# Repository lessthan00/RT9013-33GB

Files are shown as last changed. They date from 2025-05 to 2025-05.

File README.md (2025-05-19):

# RT9013-33GB

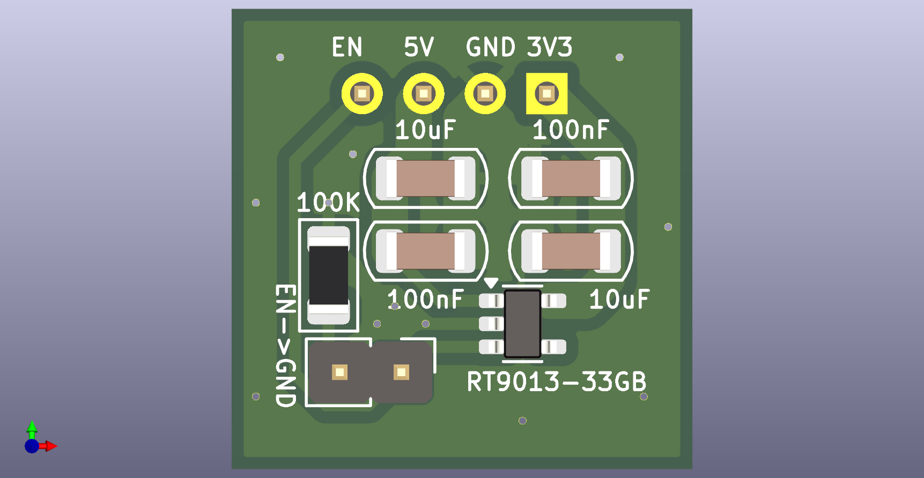
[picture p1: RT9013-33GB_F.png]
  
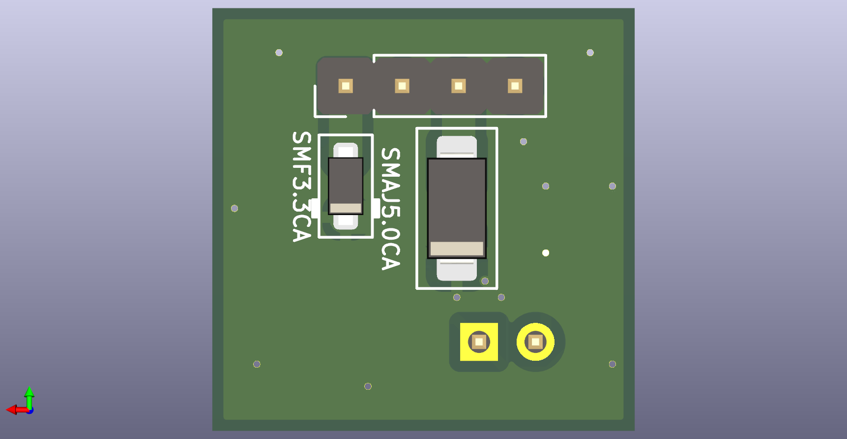
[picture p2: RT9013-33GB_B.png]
  
  

[RT9013-33GB](https://www.jlc-smt.com/lcsc/detail?componentCode=C47773)
LDO
VIN 5.5V
VOUT 3.3V
IOUT 0.5A
package SOT-23-5
accuracy 2%
IQ 50uA
VD 250mV@500mA
ENL 0.6V
ENH 1.6V
IEN 0.1uA -> 100K电阻

引脚定义
1-VIN
2-GND
3-EN
4-NC
5-VOUT

## ME6211C33M5G-N board = RT9013-33GB

[ME6211C33M5G-N](https://www.jlc-smt.com/lcsc/detail?componentCode=C82942)
LDO
VIN 6V
VOUT 3.3V
IOUT 300mA
package SOT-23-5
accuracy 2%
IQ 60uA
VD 260mV@200mA
ENL 0.5V
ENH 1V
IEN 应该是uA -> 100K电阻
Vn 50uVrms

引脚定义
1-VIN
2-GND
3-EN
4-NC
5-VOUT

## ME6210A33PG borad change from AMS1117-3V3

[ME6210A33PG](https://www.jlc-smt.com/lcsc/detail?componentCode=C85233)  
LDO  
VIN 18V  
VOUT 3.3V  
IOUT 500mA  
package SOT-89-3  
IQ 2.5uA  
VD 260mV@200mA  

引脚定义  
1-GND  
2-VIN  
3-VOUT  

## HT7550-1 board = ME6210A33PG  

[HT7550-1](https://www.jlc-smt.com/lcsc/detail?componentCode=C5346140)
LDO  
VIN 28V  
VOUT 5V  
IOUT 150mA  
package SOT-89-3
accuracy 2%
IQ 4uA
VD 520mA@100mA  

引脚定义  
1-GND  
2-IN  
3-VOUT  

## ME6206A33XG  borad change from AMS1117-3V3
  
[ME6206A33XG](https://www.jlc-smt.com/lcsc/detail?componentCode=C161345)  
LDO  
VIN 6V  
VOUT 3.3V  
IOUT 300mA  
package SOT-23-3  
IQ 8uA  
VD 400mV@200mA  

引脚定义  
1-GND  
2-VOUT  
3-VIN  

kciad 并无其符号, 根据封装和引脚定义, 选择自MCP1703Ax-330xxTT 这个符号派生  
封装也是取其 Package_TO_SOT_SMD:SOT-23  
输入TVS 改为 SMAJ6.0CA  

## AMS1117-3V3  borad change from HT7333
  
[AMS1117-3V3](https://www.jlc-smt.com/lcsc/detail?componentCode=C5120765)  
LDO  
  
VIN 18V  
VOUT 3.3V  
IOUT 1A  
package SOT-223  
IQ 12mA  
VD 1.4V@1A  
  
引脚引脚定义  
  
1 GND  
2 VOUT  
3 VIN  

输入TVS 改为SMAJ18CA
  
## HT7333  
  
[HT7333](https://item.szlcsc.com/323851.html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)  
  
LDO  
  
VIN 12V  
VOUT 3.3V  
IOUT 250mA  
package SOT-89-3  
IQ 3uA  
VD 90mV@40mA  
  
引脚定义  
  
1 GND  
2 VIN  
3 VOUT  
  
所以使用kciad 里面的 Regulator_Generic_GND_IN_OUT 生成符号  
  
封装采用PCM_Package_TO_SOT_SMD_AKL:SOT-89-3, 已确认封装焊盘顺序定义无误  
  
## TLV70450DBVR  
  
[TLV70450DBVR](https://www.jlc-smt.com/lcsc/detail?componentCode=C91672)  
VIN 24V  
VOUT 5V  
IOUT 150mA  
IQ 4.5uA  
VD 1.1V@100mA  
package SOT-23-5  
  
1-GND  
2-IN  
3-OUT  
4-NC  
5-NC  
  
这样的封装的引脚定义是很少的,基本上只有TLV70450DBVR,甚至需要自己绘制封装...  

## KP3310SGA

[KP3310SGA](http://www.kiwiinst.com/productinfo/1249602.html)  
高压斩波 + LDOLDO  
VIN 80~305VAC  
VOUT 5V/3.3V/2.7V  
IOUT 30mA  
耐压 650V MOS  
RS(ON) 9.5Ω  
IQ 130uA  
无法获取详细资料,放弃做板子

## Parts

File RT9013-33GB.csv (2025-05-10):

Reference | Qty | Value | DNP | Exclude from BOM | Exclude from Board | Footprint | Datasheet
C1,C3 | 2 | 10uF |  |  |  | PCM_Capacitor_SMD_AKL:C_1206_3216Metric | ~
C2,C4 | 2 | 100nF |  |  |  | PCM_Capacitor_SMD_AKL:C_1206_3216Metric | ~
D1 | 1 | SMAJ5.0CA |  |  |  | PCM_Diode_SMD_AKL:D_SMA_TVS | https://www.tme.eu/Document/dbc72d81c249fe51b6ab42300e8e06d0/SMAJ_ser.pdf
D2 | 1 | SMF3.3CA |  |  |  | PCM_Diode_SMD_AKL:D_SOD-123F | https://item.szlcsc.com/48682096.html?fromZone=s_s__%2522SMF3.3CA%2522
J2 | 1 | Conn_01x02 |  |  |  | Connector_PinHeader_2.54mm:PinHeader_1x02_P2.54mm_Vertical | ~
J3 | 1 | Conn_01x04 |  |  |  | Connector_PinHeader_2.54mm:PinHeader_1x04_P2.54mm_Vertical | ~
R1 | 1 | 100K |  |  |  | PCM_Resistor_SMD_AKL:R_1206_3216Metric | ~
U1 | 1 | RT9013-33GB |  |  |  | Package_TO_SOT_SMD:SOT-23-5 | https://www.jlc-smt.com/lcsc/detail?componentCode=C47773

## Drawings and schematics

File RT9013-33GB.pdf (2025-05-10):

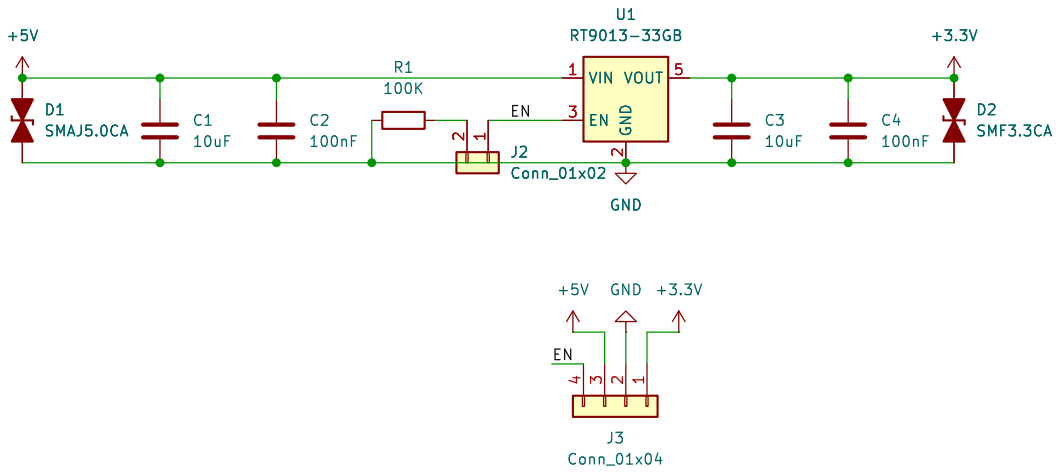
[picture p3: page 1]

Id: 1/1 Title: File: RT9013-33GB.kicad_sch Sheet: /

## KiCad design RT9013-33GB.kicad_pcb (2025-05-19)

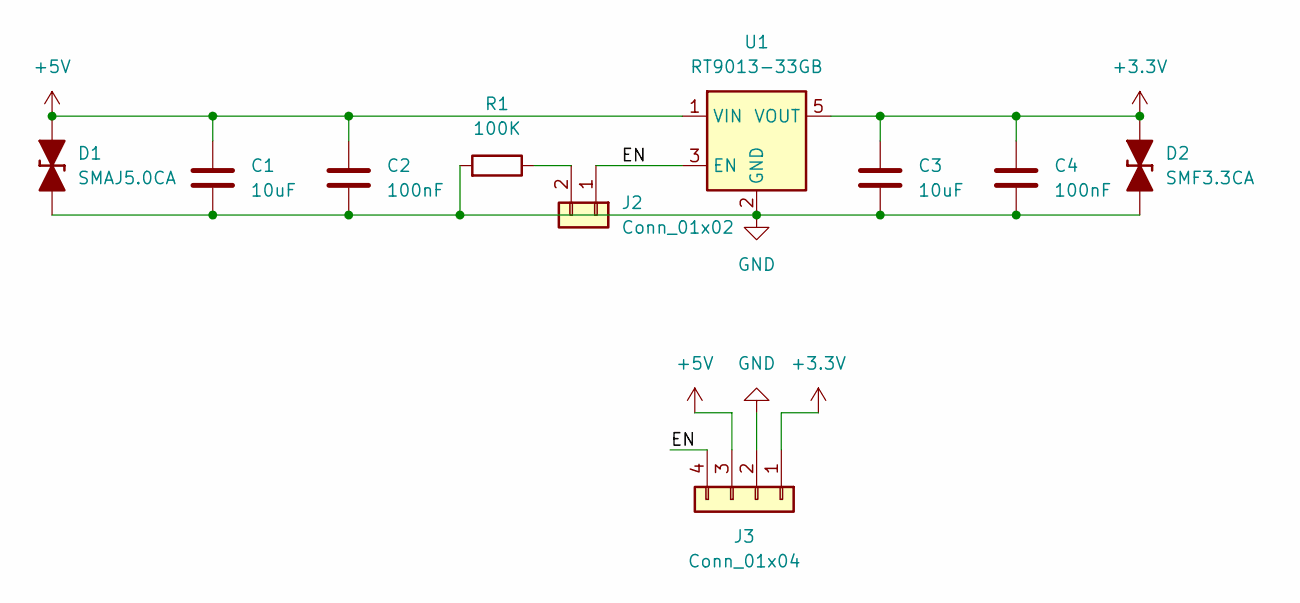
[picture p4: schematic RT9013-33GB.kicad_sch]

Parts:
C1, C3: 10uF; C_1206_3216Metric
C2, C4: 100nF; C_1206_3216Metric
D1: SMAJ5.0CA; D_SMA_TVS
D2: SMF3.3CA; D_SOD-123F
J2: Conn_01x02; PinHeader_1x02_P2.54mm_Vertical
J3: Conn_01x04; PinHeader_1x04_P2.54mm_Vertical
R1: 100K; R_1206_3216Metric
U1: RT9013-33GB; SOT-23-5

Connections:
+3.3V: C3.1, C4.1, D2.2 (A), J3.1, U1.5 (VOUT)
+5V: C1.1, C2.1, D1.2 (A), J3.3, U1.1 (VIN)
/EN: J2.1, J3.4, U1.3 (EN)
GND: C1.2, C2.2, C3.2, C4.2, D1.1 (K), D2.1 (K), J3.2, R1.1, U1.2 (GND)
unnamed: J2.2, R1.2

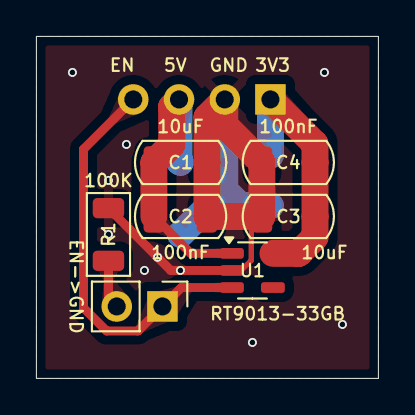
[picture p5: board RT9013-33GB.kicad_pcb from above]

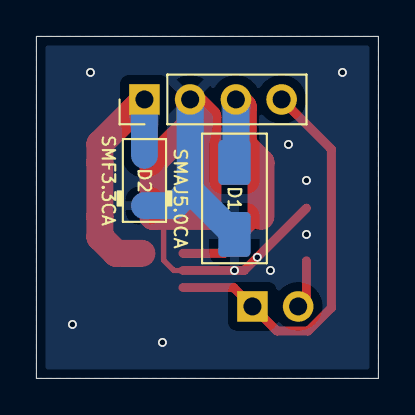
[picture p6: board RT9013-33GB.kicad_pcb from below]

Board: 2 copper layers, 19.0 x 19.0 mm, 10 parts (3 on the bottom side), 5 nets.
